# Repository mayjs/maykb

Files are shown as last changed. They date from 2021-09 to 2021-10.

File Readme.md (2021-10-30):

#  Maykb - a custom split keyboard for ISO-DE users
Maykb is a split keyboard using a staggered ISO layout including the ISO-Enter. Other features are one duplicated column in the middle (for people who don't always use the same finger for those middle keys) and the inclusion of an additional key left of the `h` which I use as a backspace key.

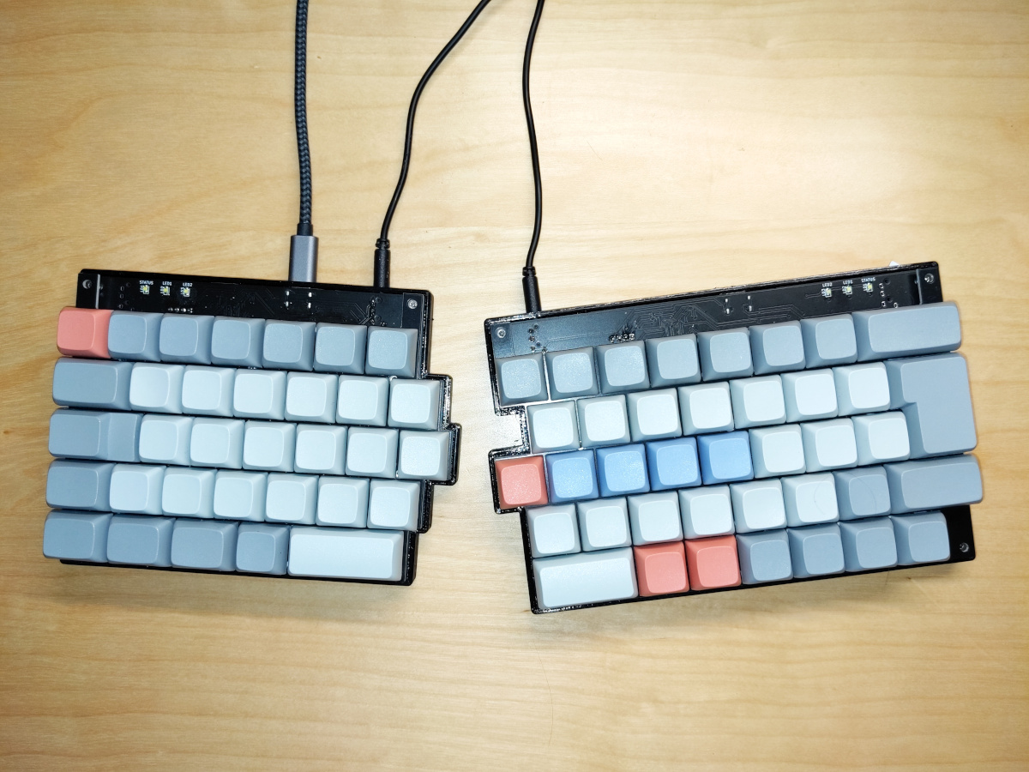
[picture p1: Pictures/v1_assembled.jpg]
Assembled Keyboard


## PCB
The PCBs for maykb are based on a STM32F103 and Cherry MX switches.
Both halves communicate using a UART interface and are equipped to be chainable, i.e. you could chain together more keyboards so you could add a numpad or a dedicated macropad if you wanted to.

There is also no fixed host MCU; both sides can act as the host and communicate over USB.

The initial revision of the PCB has one flaw: The voltage regulator for the MCU is not enabled properly due to a enable pin polarity mistake. Fixing this mistake involves lifting a pin of that regulator and wiring it properly.
I plan to replace the regulator eventually and fix the schematic and layout at that point as well.
As far as I know, there are no other hardware issues that would keep you from building one of these keyboards.

## Firmware
### Application
The firmware for the keyboard is written in Rust and uses [keyberon](https://github.com/TeXitoi/keyberon).
You need to build two different firmware versions for the left and right side so the firmware knows which part of the matrix it's working on.

### Bootloader
I'm using a slightly modified version of the [stm32duino-bootloader](https://github.com/rogerclarkmelbourne/STM32duino-bootloader).
This allows easy DFU flashing when you change the firmware.
The bootloader can be entered by holding the top left key of each side or by holding down the bootloader key on the bottom side of the PCB.

## Construction
The maykb case is designed to be 3D-printed and design files are available as OpenSCAD code.
It should be easy to adjust the code to allow for different screw tolerances or even brass screw inserts.

As a small novelty, the plates can be manufactured as aluminium PCBs (I had good results with JLCPCB), which is cheaper than all laser cutting services I was able to locate.
It should also be possible to export the plate PCB files as a DXF file and use another fabrication technique.

The PCB is a simple 1.6mm thick two layer PCB and should be easily manufactured at any prototyping company.

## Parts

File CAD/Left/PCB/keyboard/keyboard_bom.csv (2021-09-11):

Comment | Designator | Footprint | LCSC
CL1 | C10 | Capacitor_SMD:C_0603_1608Metric_Pad1.08x0.95mm_HandSolder | C22397
CL2 | C11 | Capacitor_SMD:C_0603_1608Metric_Pad1.08x0.95mm_HandSolder | C22397
100nF | C1,C2,C3,C4,C7,C9 | Capacitor_SMD:C_0805_2012Metric_Pad1.18x1.45mm_HandSolder | C28233
4.7uF - 10uF | C5 | Capacitor_SMD:C_0805_2012Metric_Pad1.18x1.45mm_HandSolder | C15850
1uF | C6,C8 | Capacitor_SMD:C_0603_1608Metric_Pad1.08x0.95mm_HandSolder | C1592
USB_C_Receptacle_USB2.0 | J1 | Connector_USB:USB_C_Receptacle_HRO_TYPE-C-31-M-12 | C165948
Debug | J2 | Connector_PinHeader_2.54mm:PinHeader_1x04_P2.54mm_Horizontal
Conn_Left | J3 | Random Keyboard Parts:PJ-3200B-4A-TRRS | C136687
Conn_Right | J4 | Random Keyboard Parts:PJ-3200B-4A-TRRS | C136687
LED | LD1,LD2,LD3 | LED_SMD:LED_0805_2012Metric_Pad1.15x1.40mm_HandSolder | C110099
SW_SPST | PB1 | Button_Switch_SMD:SW_SPST_TL3342
RESET | PB2 | Button_Switch_SMD:SW_SPST_TL3342
RExt | R12 | Resistor_SMD:R_0603_1608Metric_Pad0.98x0.95mm_HandSolder | C23228
10k | R1,R2,R3 | Resistor_SMD:R_0603_1608Metric_Pad0.98x0.95mm_HandSolder | C25804
5.1k | R4,R5 | Resistor_SMD:R_0603_1608Metric_Pad0.98x0.95mm_HandSolder | C23186
1.5k | R6 | Resistor_SMD:R_0603_1608Metric_Pad0.98x0.95mm_HandSolder | C22843
20R | R7,R8 | Resistor_SMD:R_0603_1608Metric_Pad0.98x0.95mm_HandSolder | C22950
510R | R9,R10,R11 | Resistor_SMD:R_0603_1608Metric_Pad0.98x0.95mm_HandSolder | C23193
TestPoint | TP1 | TestPoint:TestPoint_Pad_D1.0mm
USB_SBU1 | TP2 | TestPoint:TestPoint_Pad_D1.0mm
USB_SBU2 | TP3 | TestPoint:TestPoint_Pad_D1.0mm
LN1154 | U1 | Package_TO_SOT_SMD:SOT-23-5 | C236376
STM32F103C8Tx | U2 | Package_QFP:LQFP-48_7x7mm_P0.5mm | C77994
8MHz | Y1 | Crystal:Crystal_SMD_HC49-SD | C115962
1N4148 | D1,D2,D3,D4,D5,D6,D7,D8,D9,D10,D11,D12,D13,D14,D15,D16,D17,D18,D19,D20,D21,D22,D23,D24,D25,D26,D27,D28,D29,D30,D31,D32,D33,D34,D35,D36,D37,D38,D39 |  | C2128

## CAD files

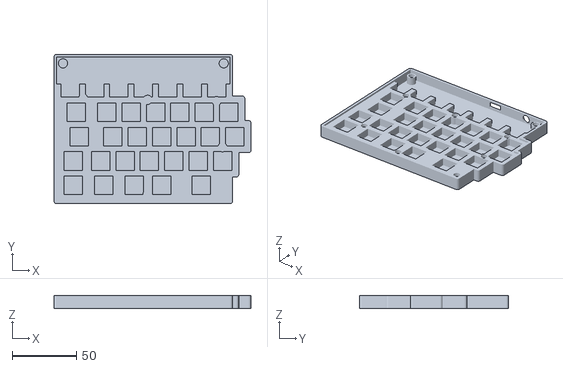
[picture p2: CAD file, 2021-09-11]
CAD/Left/Case/case_left.stl
153.8 x 116.6 x 10.0

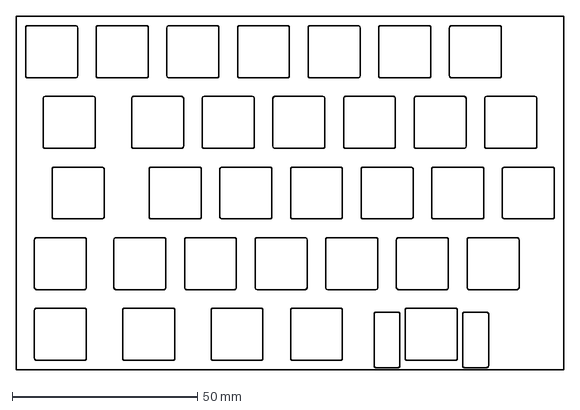
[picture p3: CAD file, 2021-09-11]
CAD/Left/Plate/#plate-20210801-131349.dxf
147.6 x 95.2 mm

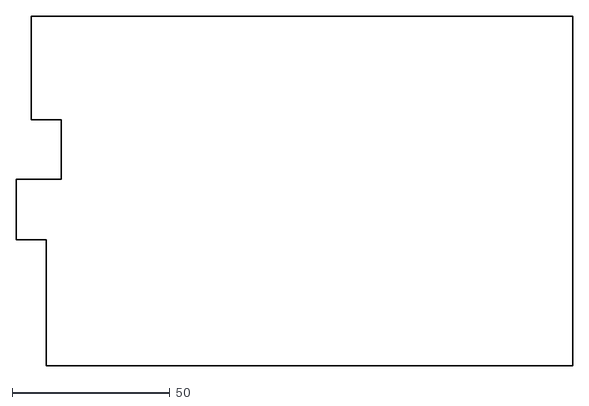
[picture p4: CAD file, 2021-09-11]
CAD/Right/Case/outline.dxf
176.5 x 110.7

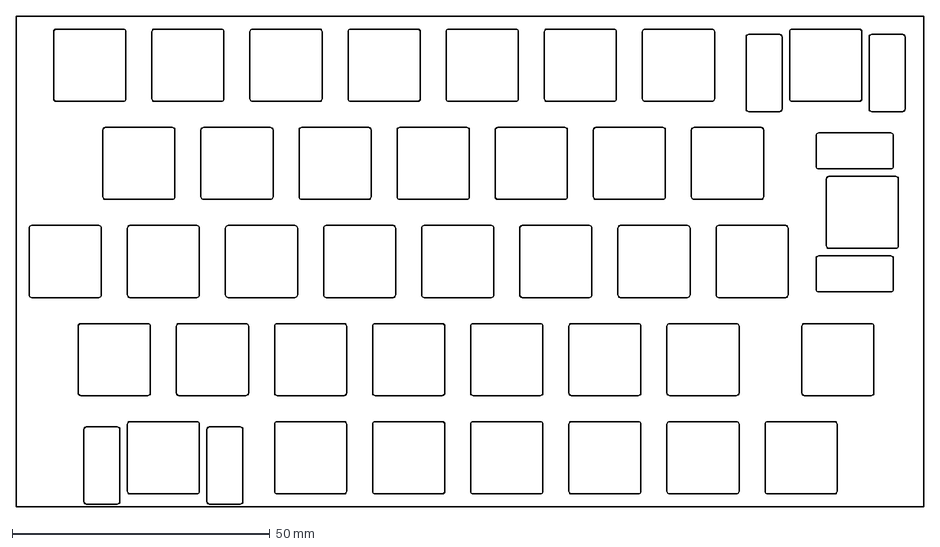
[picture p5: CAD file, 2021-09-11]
CAD/Right/Plate/plate-20210801-010555.dxf
176.2 x 95.2 mm

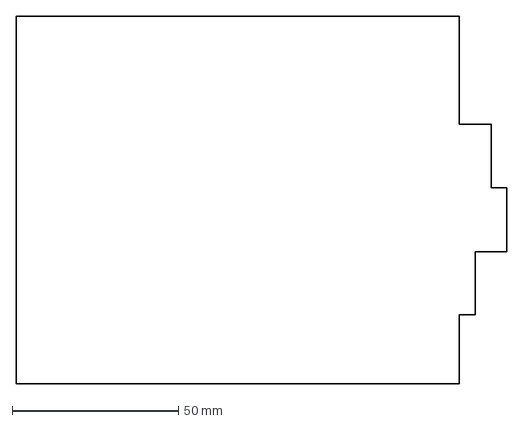
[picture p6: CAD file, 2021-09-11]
CAD/Left/Case/outline.dxf
147.8 x 110.6 mm

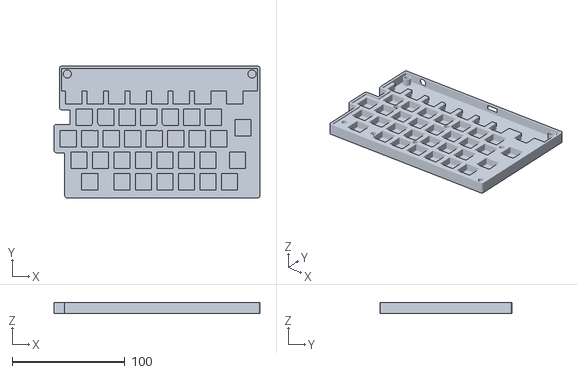
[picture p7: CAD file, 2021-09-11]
CAD/Right/Case/case_right.stl
182.5 x 116.7 x 10.0

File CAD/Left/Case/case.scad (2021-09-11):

use <mayscadlib/positioning.scad>;
use <mayscadlib/2d/shapes.scad>;
use <./footprint_centers.scad>;

$fn=100;
wall = 2;
bot_plane=wall;
play = .2;
pcb_thickness = 1.6;
screw_length=8;
pcb_pos = screw_length-pcb_thickness;
audio_jack_dia = 5;
audio_plug_dia = 6.2;
usb_c_jack_bounds = [10, 4];
switch_cutout_size = [14.5,14.5];

mounting_positions = [
  [4.06,    -4.06],
  [129.54,  -4.06],
  [19.81,   -31.50],
  [70.10,   -32.51],
  [123.95,  -33.53],
  [128.52,  -69.60],
  [23.11,   -89.92],
  [70.10,   -106.17],
  [129.54,  -106.17]
];

audio_jacks = [
  //17.65, // Skip the left jack hole
  115.72,
];

usb_c_jack = 84.56;

footprint_origin = [69.7548, 44.547];

module outline(play=5*play) {
  offset(delta=play)
  import("./outline.dxf");
}

module wall_2d() {
  difference() {
    offset(r=wall)
    outline();
    outline();
  }
}

function screw_post_outer_rad(screw_dia=3) = ((screw_dia+play)/2)+wall;

module screw_post(screw_grip=2.5, screw_length=screw_length-pcb_thickness, screw_dia=3) {
  grip_rad = (screw_dia + play)/2;
  linear_extrude(height=screw_grip)
  difference() {
    circle(r=screw_post_outer_rad(screw_dia=screw_dia));
    circle(r=grip_rad);
  }
  lift(screw_grip)
  linear_extrude(height=screw_length-screw_grip)
  difference() {
    circle(r=grip_rad+wall);
    circle(r=grip_rad+1);
  }
}

module audio_jack_cutout() {
  cutout_h = wall + play*5;
  function rad(assumed) = (assumed+play)/2;
  translate([0,cutout_h,0])
  lift(pcb_pos-rad(audio_jack_dia)+bot_plane)
  rotate([90,0,0])
  cylinder(r2=rad(audio_plug_dia), r1=rad(audio_plug_dia*1.2), h=cutout_h);
}

module usb_c_jack_cutout() {
  cutout_h = wall + play*5;
  real_bounds = usb_c_jack_bounds + [2*play, 2*play];

  translate([0,cutout_h,0])
  lift(pcb_pos-real_bounds[1]+bot_plane)
  rotate([90,0,0])
  translate([0,real_bounds[1]/2, cutout_h])
  mirror([0,0,1])
  linear_extrude(height=cutout_h, scale=1.2)
  rounded_square(size=real_bounds, corner_rad=.5, center=true);
}

module stabilization_area() {
  difference() {
    intersection(){
      outline();
      // Cut off a bit of the top post switch area
      translate([-50,-1020])
      square(size=[1000,1000]);
    }
    place([for(k=kb_footprint_centers()) [k[0] - footprint_origin[0], -k[1]+footprint_origin[1]]])
    square(switch_cutout_size,center=true);
    place(mounting_positions)
    circle(screw_post_outer_rad());
  }
}


difference() {
  union() {

    linear_extrude(height=bot_plane) {
      wall_2d();
      outline();
    }
    translate([0,0,bot_plane])
    linear_extrude(height=pcb_pos + pcb_thickness) {
      wall_2d();
    }
  }

  place([for(x=audio_jacks) [x,0,0]])
  audio_jack_cutout();

  translate([usb_c_jack,0,0])
  usb_c_jack_cutout();
}
lift(bot_plane-.01)
linear_extrude(height=pcb_pos)
stabilization_area();

place(mounting_positions) {
  lift(bot_plane)
  screw_post();
}

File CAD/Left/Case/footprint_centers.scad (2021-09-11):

function kb_footprint_centers() = [
    [107.931,86.722],
    [84.1185,86.722],
    [193.656,67.672],
    [174.606,67.672],
    [155.556,67.672],
    [136.506,67.672],
    [181.74975,143.872],
    [150.7935,143.872],
    [129.36225,143.872],
    [105.54975,143.872],
    [117.456,67.672],
    [81.73725,143.872],
    [198.4185,124.822],
    [179.3685,124.822],
    [160.3185,124.822],
    [141.2685,124.822],
    [122.2185,124.822],
    [103.1685,124.822],
    [81.73725,124.822],
    [207.9435,105.772],
    [188.8935,105.772],
    [98.406,67.672],
    [169.8435,105.772],
    [150.7935,105.772],
    [131.7435,105.772],
    [112.6935,105.772],
    [86.49975,105.772],
    [203.181,86.722],
    [184.131,86.722],
    [165.081,86.722],
    [146.031,86.722],
    [126.981,86.722],
    [79.356,67.672],
    [181.74975,143.872],
];

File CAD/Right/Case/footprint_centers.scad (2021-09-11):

function kb_footprint_centers() = [
    [52.6225,94.469],
    [185.9725,75.419],
    [157.3975,75.419],
    [138.3475,75.419],
    [119.2975,75.419],
    [100.2475,75.419],
    [181.21,151.619],
    [162.16,151.619],
    [143.11,151.619],
    [124.06,151.619],
    [105.01,151.619],
    [85.96,151.619],
    [57.385,151.619],
    [188.35375,132.569],
    [162.16,132.569],
    [143.11,132.569],
    [81.1975,75.419],
    [124.06,132.569],
    [105.01,132.569],
    [85.96,132.569],
    [66.91,132.569],
    [47.86,132.569],
    [171.685,113.519],
    [152.635,113.519],
    [133.585,113.519],
    [114.535,113.519],
    [95.485,113.519],
    [62.1475,75.419],
    [76.435,113.519],
    [57.385,113.519],
    [38.335,113.519],
    [193.11625,103.994],
    [166.9225,94.469],
    [147.8725,94.469],
    [128.8225,94.469],
    [109.7725,94.469],
    [90.7225,94.469],
    [71.6725,94.469],
    [43.0975,75.419],
    [185.9725,75.419],
    [57.385,151.619],
    [193.11625,103.994],
];

function kb_mount_centers() = [
    [180.25,102.068],
    [62.25,103.068],
    [114.25,142.068],
    [119.25,103.068],
    [75.25,153.068],
    [42.25,153.068],
    [37.49,56.324],
    [201.232,56.324],
    [201.232,159.068],
];

function audio_jack_x() = [
    51.232,
    187.232,
];

function usb_c_x() = [
    129.681001,
];

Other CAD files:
CAD/Left/Plate/vec/#plate-Edge_Cuts.dxf
CAD/Right/Case/case.scad
CAD/Left/Plate/plate-20210801-131349.dxf
CAD/Left/Plate/vec/plate-Edge_Cuts.dxf

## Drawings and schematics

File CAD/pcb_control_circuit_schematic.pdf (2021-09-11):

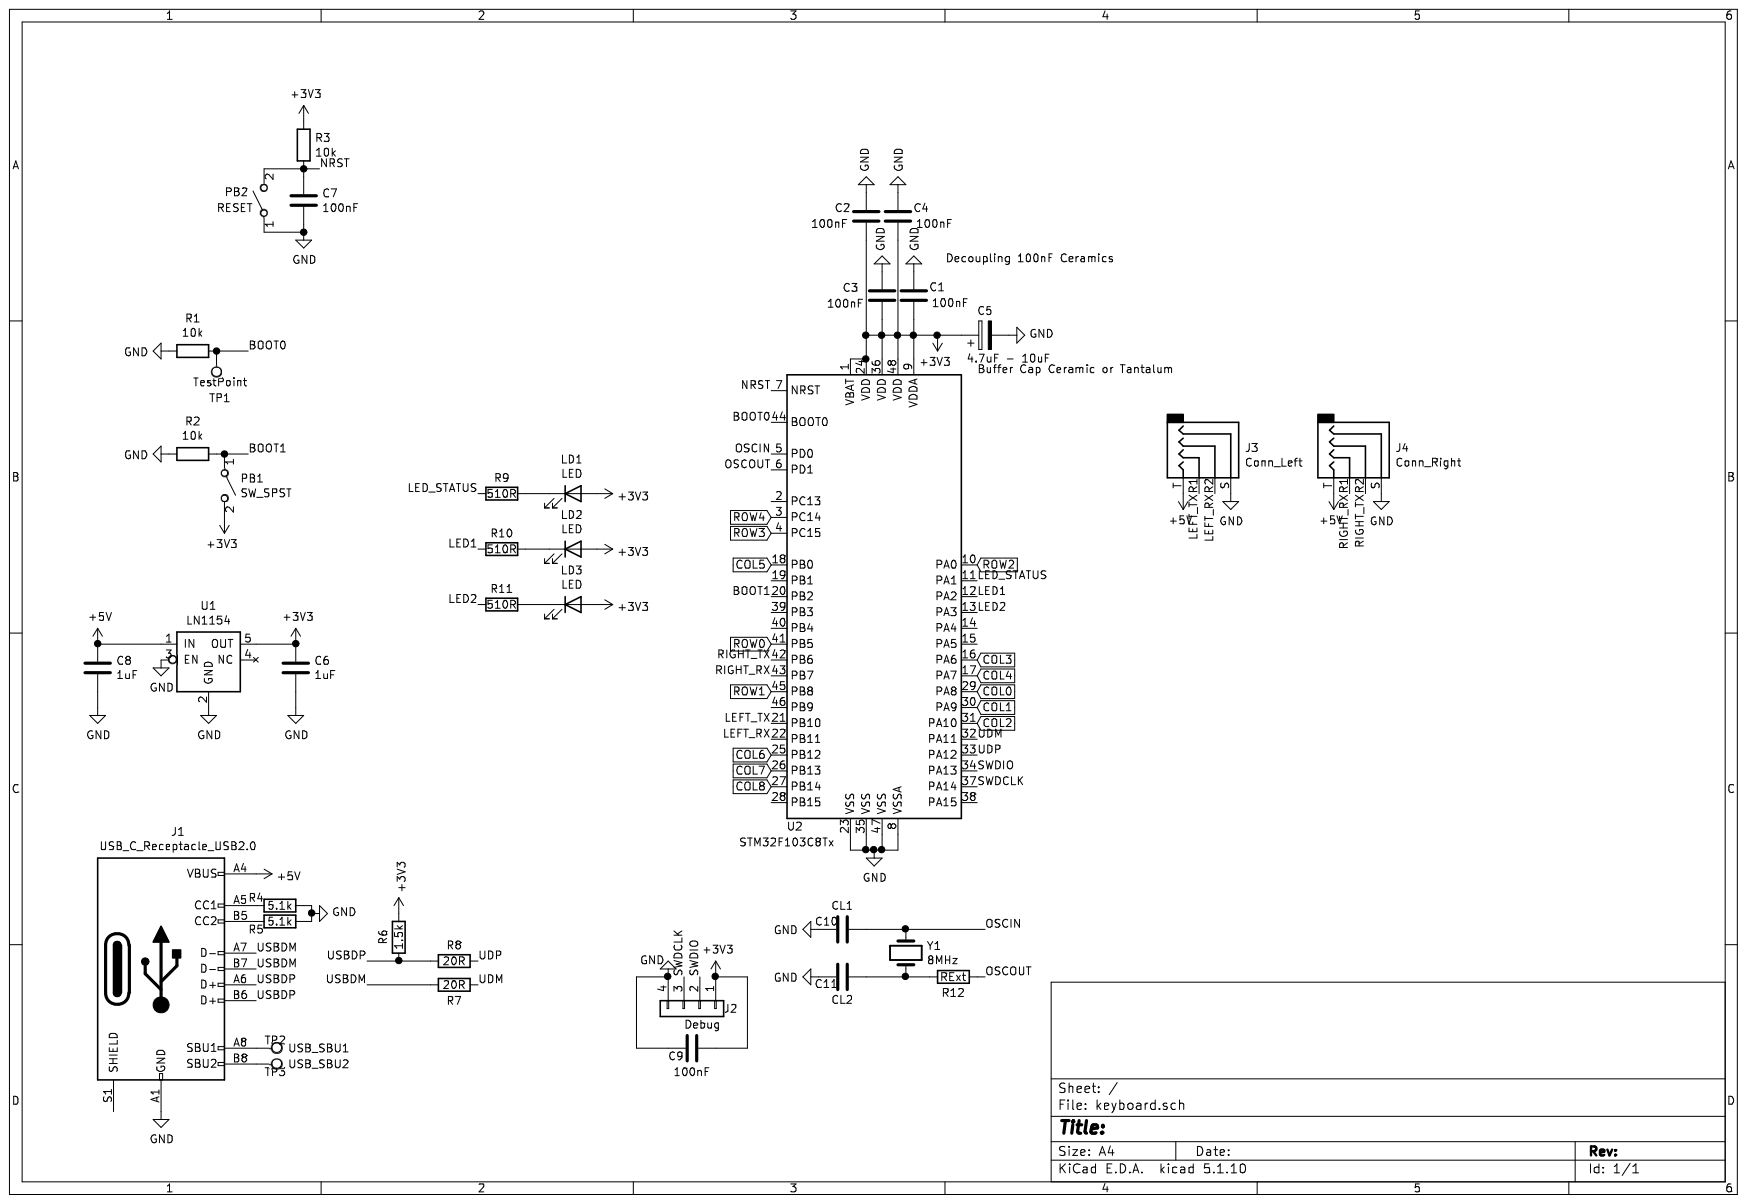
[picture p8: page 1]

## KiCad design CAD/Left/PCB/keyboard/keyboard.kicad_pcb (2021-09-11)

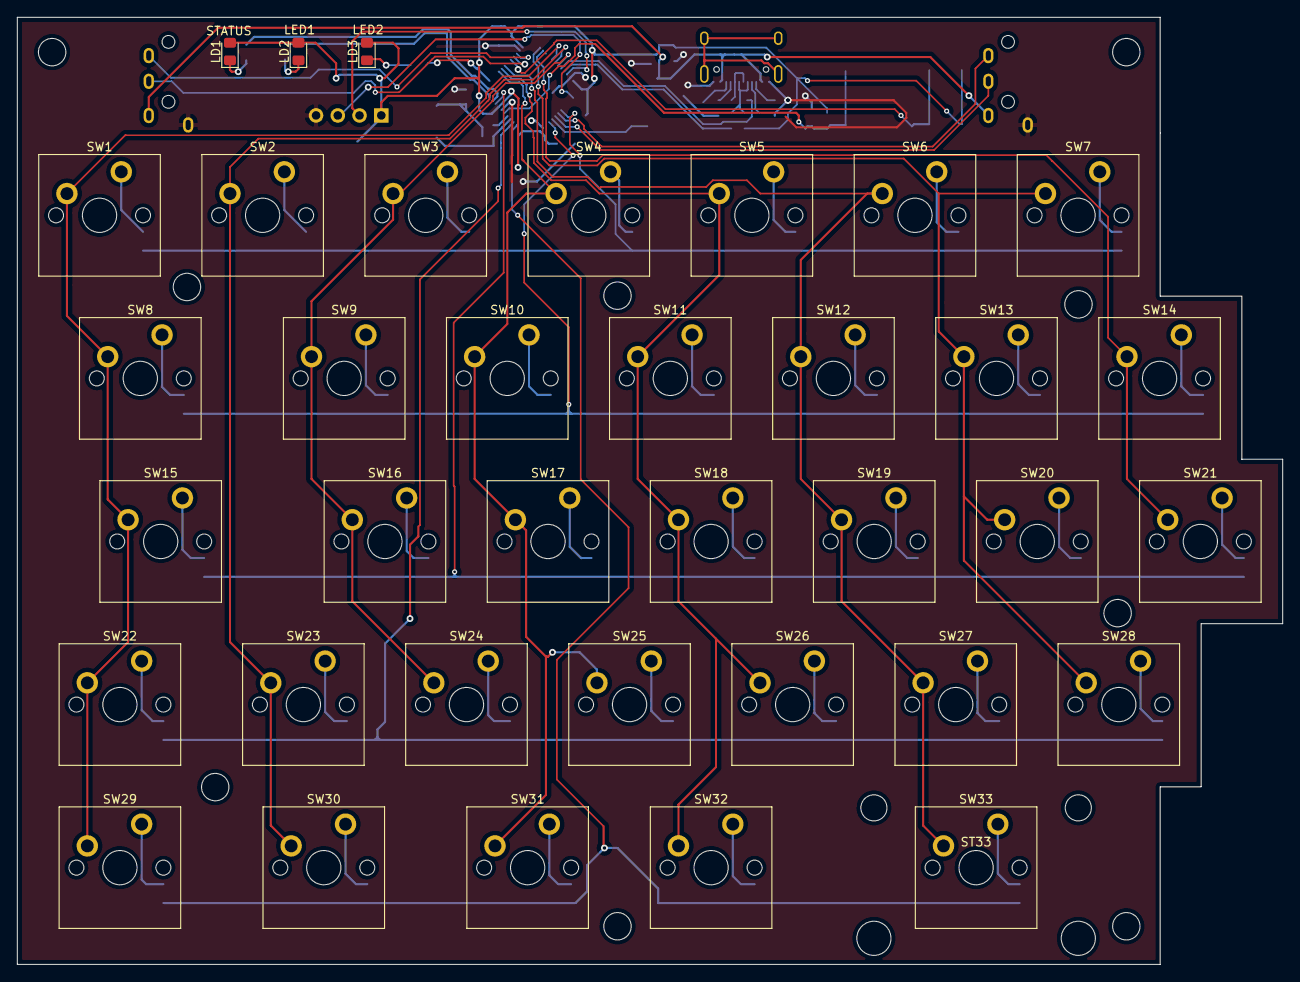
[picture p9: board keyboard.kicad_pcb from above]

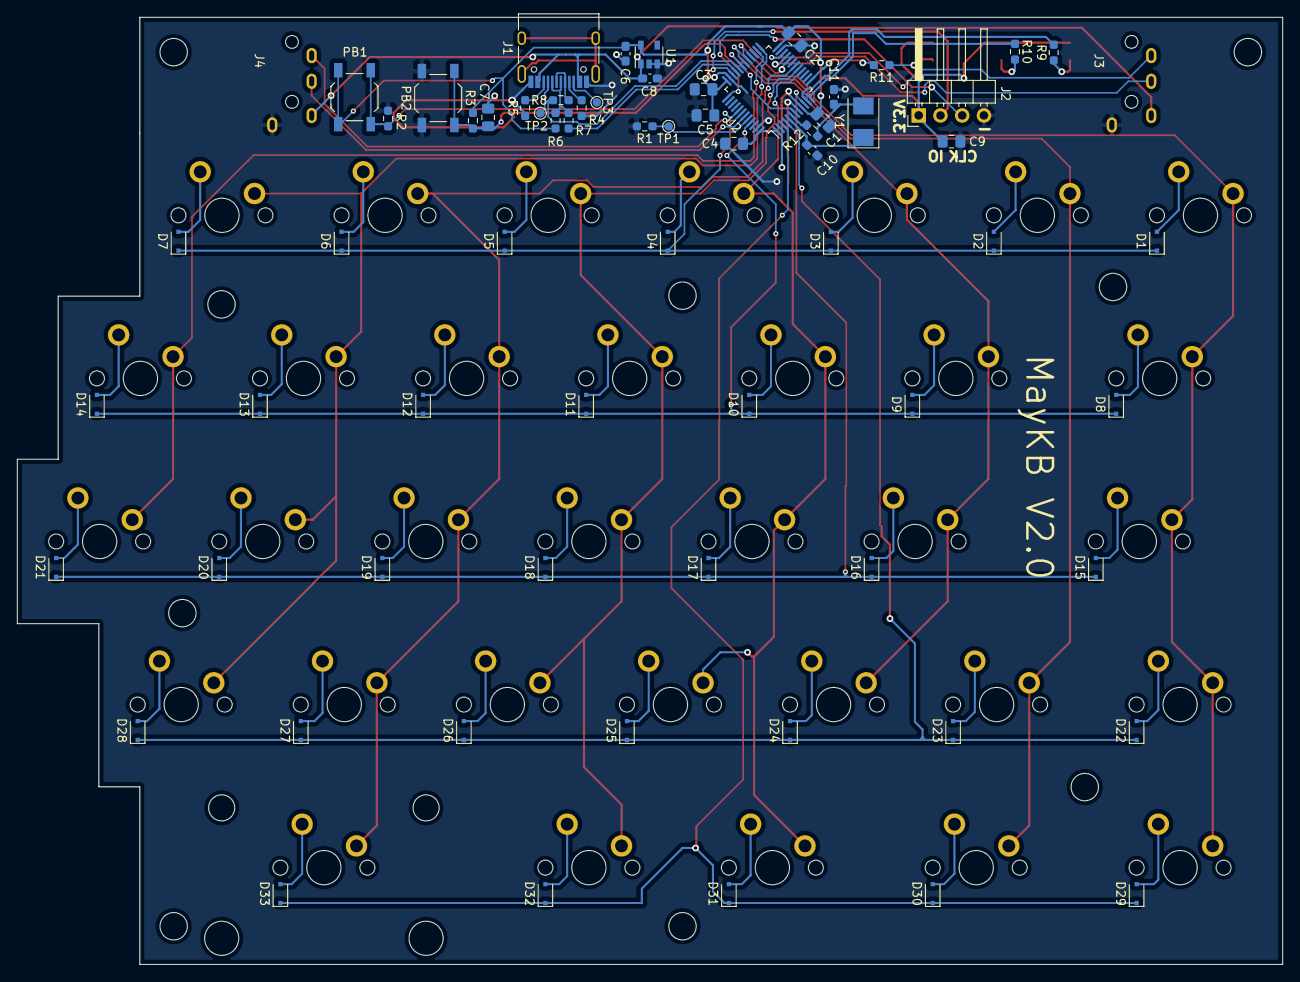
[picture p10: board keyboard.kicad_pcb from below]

Board: 2 copper layers, 147.8 x 110.6 mm, 105 parts (68 on the bottom side), 75 nets.

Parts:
C1, C2, C3, C4, C7, C9: 100nF; C_0805_2012Metric_Pad1.18x1.45mm_HandSolder
C5: 4.7uF - 10uF; C_0805_2012Metric_Pad1.18x1.45mm_HandSolder
C6, C8: 1uF; C_0603_1608Metric_Pad1.08x0.95mm_HandSolder
C10: CL1; C_0603_1608Metric_Pad1.08x0.95mm_HandSolder
C11: CL2; C_0603_1608Metric_Pad1.08x0.95mm_HandSolder
D1, D2, D3, D4, D5, D6, D7, D8, D9, D10, D11, D12, D13, D14, D15, D16, D17, D18, D19, D20, D21, D22, D23, D24, D25, D26, D27, D28, D29, D30, D31, D32, D33: D; D_SOD-323F
J1: USB_C_Receptacle_USB2.0; USB_C_Receptacle_HRO_TYPE-C-31-M-12
J2: Debug; PinHeader_1x04_P2.54mm_Horizontal
J3: Conn_Left; PJ-3200B-4A-TRRS
J4: Conn_Right; PJ-3200B-4A-TRRS
LD1, LD2, LD3: LED; LED_0805_2012Metric_Pad1.15x1.40mm_HandSolder
PB1: SW_SPST; SW_SPST_TL3342
PB2: RESET; SW_SPST_TL3342
R1, R2, R3: 10k; R_0603_1608Metric_Pad0.98x0.95mm_HandSolder
R4, R5: 5.1k; R_0603_1608Metric_Pad0.98x0.95mm_HandSolder
R6: 1.5k; R_0603_1608Metric_Pad0.98x0.95mm_HandSolder
R7, R8: 20R; R_0603_1608Metric_Pad0.98x0.95mm_HandSolder
R9, R10, R11: 510R; R_0603_1608Metric_Pad0.98x0.95mm_HandSolder
R12: RExt; R_0603_1608Metric_Pad0.98x0.95mm_HandSolder
ST33: MountingHole; Stabilizer_Cherry_MX_2u
SW1, SW2, SW3, SW4, SW5, SW6, SW7, SW9, SW10, SW11, SW12, SW13, SW14, SW16, SW17, SW18, SW19, SW20, SW21, SW23, SW24, SW25, SW26, SW27, SW28, SW32: SW_Push; SW_Cherry_MX_PCB_1.00u
SW8: SW_Push; SW_Cherry_MX_PCB_1.50u
SW15: SW_Push; SW_Cherry_MX_PCB_1.75u
SW22, SW29, SW30, SW31: SW_Push; SW_Cherry_MX_PCB_1.25u
SW33: SW_Push; SW_Cherry_MX_PCB_2.25u
TP1: TestPoint; TestPoint_Pad_D1.0mm
TP2: USB_SBU1; TestPoint_Pad_D1.0mm
TP3: USB_SBU2; TestPoint_Pad_D1.0mm
U1: LN1154; SOT-23-5
U2: STM32F103C8Tx; LQFP-48_7x7mm_P0.5mm
Y1: 8MHz; Crystal_SMD_5032-2Pin_5.0x3.2mm

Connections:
+3V3: C1.1, C2.1, C3.2, C4.1, C5.1, C6.1, C9.1, J2.1, LD1.2, LD2.2, LD3.2, PB1.2, R3.1, R6.1, U1.5, U2.1, U2.9, U2.24, U2.36, U2.48
+5V: C8.1, J1.A4, J1.A9, J1.B4, J1.B9, J3.T, J4.T, U1.1
/BOOT0: R1.1, TP1.1, U2.44
/BOOT1: PB1.1, R2.1, U2.20
/LED1: R10.2, U2.12
/LED2: R11.2, U2.13
/LED_STATUS: R9.2, U2.11
/LEFT_RX: J3.R2, U2.22
/LEFT_TX: J3.R1, U2.21
/NRST: C7.1, PB2.2, R3.2, U2.7
/OSCIN: C10.1, U2.5, Y1.1
/OSCOUT: R12.1, U2.6
/RIGHT_RX: J4.R1, U2.43
/RIGHT_TX: J4.R2, U2.42
/SWDCLK: J2.3, U2.37
/SWDIO: J2.2, U2.34
/UDM: R8.1, U2.32
/UDP: R7.1, U2.33
/USBDM: J1.A7, J1.B7, R8.2
/USBDP: J1.A6, J1.B6, R6.2, R7.2
COL0: SW1.1, SW8.1, SW15.1, SW22.1, SW29.1, U2.29
COL1: SW2.1, SW23.1, SW30.1, U2.30
COL2: SW3.1, SW9.1, SW16.1, SW24.1, U2.31
COL3: SW4.1, SW10.1, SW17.1, SW25.1, SW31.1, U2.16
COL4: SW5.1, SW11.1, SW18.1, SW26.1, SW32.1, U2.17
COL5: SW6.1, SW12.1, SW19.1, SW27.1, SW33.1, U2.18
COL6: SW7.1, SW13.1, SW20.1, SW28.1, U2.25
COL7: SW14.1, SW21.1, U2.26
GND: C1.2, C2.2, C3.1, C4.2, C5.2, C6.2, C7.2, C8.2, C9.2, C10.2, C11.1, J1.A1, J1.A12, J1.B1, J1.B12, J2.4, J3.S, J4.S, PB2.1, R1.2, R2.2, R4.1, R5.1, U1.2, U1.3, U2.8, U2.23, U2.35, U2.47
unnamed: D1.2, SW1.2
unnamed: D2.2, SW2.2
unnamed: D3.2, SW3.2
unnamed: D4.2, SW4.2
unnamed: D5.2, SW5.2
unnamed: D6.2, SW6.2
unnamed: D7.2, SW7.2
unnamed: D8.2, SW8.2
unnamed: D9.2, SW9.2
unnamed: D10.2, SW10.2
unnamed: D11.2, SW11.2
unnamed: D12.2, SW12.2
unnamed: D13.2, SW13.2
unnamed: D14.2, SW14.2
unnamed: D15.2, SW15.2
unnamed: D16.2, SW16.2
unnamed: D17.2, SW17.2
unnamed: D18.2, SW18.2
unnamed: D19.2, SW19.2
unnamed: D20.2, SW20.2
unnamed: D21.2, SW21.2
unnamed: D22.2, SW22.2
unnamed: D23.2, SW23.2
unnamed: D24.2, SW24.2
unnamed: D25.2, SW25.2
unnamed: D26.2, SW26.2
unnamed: D27.2, SW27.2
unnamed: D28.2, SW28.2
unnamed: D29.2, SW29.2
unnamed: D30.2, SW30.2
unnamed: D31.2, SW31.2
unnamed: D32.2, SW32.2
unnamed: D33.2, SW33.2
unnamed: C11.2, R12.2, Y1.2
unnamed: J1.A5, R4.2
unnamed: J1.A8, TP2.1
unnamed: J1.B5, R5.2
unnamed: J1.B8, TP3.1
unnamed: LD1.1, R9.1
unnamed: LD2.1, R10.1
unnamed: LD3.1, R11.1
ROW0: D1.1, D2.1, D3.1, D4.1, D5.1, D6.1, D7.1, U2.41
ROW1: D8.1, D9.1, D10.1, D11.1, D12.1, D13.1, D14.1, U2.45
ROW2: D15.1, D16.1, D17.1, D18.1, D19.1, D20.1, D21.1, U2.10
ROW3: D22.1, D23.1, D24.1, D25.1, D26.1, D27.1, D28.1, U2.4
ROW4: D29.1, D30.1, D31.1, D32.1, D33.1, U2.3

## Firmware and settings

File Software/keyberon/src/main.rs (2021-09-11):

#![no_main]
#![no_std]

use panic_halt as _;

use core::convert::Infallible;
use hal::prelude::*;
use hal::gpio::{Input, Output, Pxx, PullUp, PushPull, OpenDrain};
use hal::serial;
use hal::usb;
use hal::{stm32, timer};
use embedded_hal::digital::v2::OutputPin;
use keyberon::action::{k, l, m, d, Action, Action::*, HoldTapConfig};
use keyberon::debounce::Debouncer;
use keyberon::key_code::KbHidReport;
use keyberon::key_code::KeyCode::*;
use keyberon::layout::{Event, Layout};
use keyberon::matrix::{Matrix, PressedKeys};
use nb::block;
use rtic::app;
use stm32f1xx_hal as hal;
use usb_device::bus::UsbBusAllocator;
use usb_device::class::UsbClass as _;
use usb_device::device::UsbDeviceState;

type UsbClass = keyberon::Class<'static, usb::UsbBusType, ()>;
type UsbDevice = usb_device::device::UsbDevice<'static, usb::UsbBusType>;

trait ResultExt<T> {
    fn get(self) -> T;
}
impl<T> ResultExt<T> for Result<T, Infallible> {
    fn get(self) -> T {
        match self {
            Ok(v) => v,
            Err(e) => match e {},
        }
    }
}

// Taps will toggle the default layer, holding will add acurrent layer.
const FN_KEY: Action = HoldTap {
    config: HoldTapConfig::Default,
    hold: &l(1),
    tap: &d(1),
    tap_hold_interval: 0,
    timeout: 100,
};

#[rustfmt::skip]
pub static LAYERS: keyberon::layout::Layers = &[
    &[
        &[k(Grave), k(Kb1), k(Kb2), k(Kb3), k(Kb4), k(Kb5), k(Kb6), Trans, Trans, k(Kb6), k(Kb7), k(Kb8), k(Kb9), k(Kb0), k(Minus), k(Equal), Trans, k(BSpace)],
        &[k(Tab), Trans, k(Q), k(W), k(E), k(R), k(T), k(Y), Trans, Trans, k(Y), k(U), k(I), k(O), k(P), k(LBracket), k(RBracket), Trans],
        &[k(Escape), Trans, k(A), k(S), k(D), k(F), k(G), k(H), Trans, k(BSpace), k(H), k(J), k(K), k(L), k(SColon), k(Quote), k(NonUsHash), k(Enter)],
        &[k(LShift), k(NonUsBslash), k(Z), k(X), k(C), k(V), k(B), Trans, Trans, Trans, k(B), k(N), k(M), k(Comma), k(Dot), k(Slash), k(Up), k(RShift)],
        &[k(LCtrl), k(LGui), Trans, k(LAlt), FN_KEY, k(Space), Trans, Trans, Trans, Trans, k(Space), Trans, k(Enter), k(Delete), k(RAlt), k(Left), k(Down), k(Right)]
    ],
    &[
        &[Trans, k(F1), k(F2), k(F3), k(F4), k(F5), k(F6), Trans, Trans, k(F6), k(F7), k(F8), k(F9), k(F10), k(F11), k(F12), Trans, Trans],
        &[Trans, Trans, Trans, Trans, Trans, Trans, Trans, Trans, Trans, Trans, Trans, Trans, Trans, k(Kp7), k(Kp8), k(Kp9), Trans, Trans],
        &[Trans, Trans, Trans, Trans, Trans, Trans, Trans, Trans, Trans, Trans, Trans, Trans, Trans, k(Kp4), k(Kp5), k(Kp6), Trans, Trans],
        &[Trans, Trans, Trans, Trans, Trans, Trans, Trans, Trans, Trans, Trans, Trans, Trans, Trans, k(Kp1), k(Kp2), k(Kp3), Trans, Trans],
        &[Trans, Trans, Trans, Trans, d(0), Trans, Trans, Trans, Trans, Trans, Trans, Trans, Trans, Trans, k(Kp0), Trans, Trans, Trans],
    ],
];

#[derive(Debug, Clone, Copy)]
pub enum BoardType {
    Left,
    Right
}

const COLS_PER_BOARD: u8 = 9;

#[app(device = crate::hal::pac, peripherals = true)]
const APP: () = {
    struct Resources {
        usb_dev: UsbDevice,
        usb_class: UsbClass,
        matrix: Matrix<Pxx<Input<PullUp>>, Pxx<Output<PushPull>>, 9, 5>,
        debouncer: Debouncer<PressedKeys<9, 5>>,
        layout: Layout,
        timer: timer::CountDownTimer<stm32::TIM3>,

        right_tx: serial::Tx<hal::pac::USART1>,
        right_rx: serial::Rx<hal::pac::USART1>,

        left_tx: serial::Tx<hal::pac::USART3>,
        left_rx: serial::Rx<hal::pac::USART3>,

        left_buf: [u8; 4],
        right_buf: [u8; 4],

        board_type: BoardType, 

        leds: [Pxx<Output<OpenDrain>>; 3]
        /*
        transform: fn(Event) -> Event,
        tx: serial::Tx<hal::pac::USART1>,
        rx: serial::Rx<hal::pac::USART1>,
        */
    }

    #[init]
    fn init(mut c: init::Context) -> init::LateResources {
        static mut USB_BUS: Option<UsbBusAllocator<usb::UsbBusType>> = None;

        let mut flash = c.device.FLASH.constrain();
        let mut rcc = c.device.RCC.constrain();

        let mut afio = c.device.AFIO.constrain(&mut rcc.apb2);

        let clocks = rcc.cfgr
            .use_hse(8.mhz())
            .sysclk(72.mhz())
            .pclk1(36.mhz())
            .pclk2(72.mhz())
            .freeze(&mut flash.acr);

        let mut gpioa = c.device.GPIOA.split(&mut rcc.apb2);
        let mut gpiob = c.device.GPIOB.split(&mut rcc.apb2);
        let mut gpioc = c.device.GPIOC.split(&mut rcc.apb2);

        let usb = usb::Peripheral {
            usb: c.device.USB,
            pin_dm: gpioa.pa11,
            pin_dp: gpioa.pa12,
        };
        *USB_BUS = Some(usb::UsbBusType::new(usb));
        let usb_bus = USB_BUS.as_ref().unwrap();

        let usb_class = keyberon::new_class(usb_bus, ());
        let usb_dev = keyberon::new_device(usb_bus);

        let mut timer = timer::Timer::tim3(c.device.TIM3, &clocks, &mut rcc.apb1).start_count_down(1.khz());
        timer.listen(timer::Event::Update);

        let mut right_usart = serial::Serial::usart1(c.device.USART1, 
            (
                gpiob.pb6.into_alternate_push_pull(&mut gpiob.crl),
                gpiob.pb7
            ),
            &mut afio.mapr,
            serial::Config::default().baudrate(38_400.bps()).parity_even(),
            clocks,
            &mut rcc.apb2
        );
        right_usart.listen(serial::Event::Rxne);
        let (right_tx, right_rx) = right_usart.split();

        let mut left_usart = serial::Serial::usart3(c.device.USART3, 
            (
                gpiob.pb10.into_alternate_push_pull(&mut gpiob.crh),
                gpiob.pb11
            ),
            &mut afio.mapr,
            serial::Config::default().baudrate(38_400.bps()).parity_even(),
            clocks,
            &mut rcc.apb1
        );
        left_usart.listen(serial::Event::Rxne);
        let (left_tx, left_rx) = left_usart.split();

        /*
        let (pa9, pa10) = (gpioa.pa9, gpioa.pa10);
        let pins = cortex_m::interrupt::free(move |cs| {
            (pa9.into_alternate_af1(cs), pa10.into_alternate_af1(cs))
        });
        let mut serial = serial::Serial::usart1(c.device.USART1, pins, 38_400.bps(), &mut rcc);
        serial.listen(serial::Event::Rxne);
        let (tx, rx) = serial.split();
        */

        let mut matrix = Matrix::new(
            [
                gpioa.pa8.into_pull_up_input(&mut gpioa.crh).downgrade(),
                gpioa.pa9.into_pull_up_input(&mut gpioa.crh).downgrade(),
                gpioa.pa10.into_pull_up_input(&mut gpioa.crh).downgrade(),
                gpioa.pa6.into_pull_up_input(&mut gpioa.crl).downgrade(),
                gpioa.pa7.into_pull_up_input(&mut gpioa.crl).downgrade(),
                gpiob.pb0.into_pull_up_input(&mut gpiob.crl).downgrade(),
                gpiob.pb12.into_pull_up_input(&mut gpiob.crh).downgrade(),
                gpiob.pb13.into_pull_up_input(&mut gpiob.crh).downgrade(),
                gpiob.pb14.into_pull_up_input(&mut gpiob.crh).downgrade(),
            ],
            [

                gpiob.pb5.into_push_pull_output(&mut gpiob.crl).downgrade(),
                gpiob.pb8.into_push_pull_output(&mut gpiob.crh).downgrade(),
                gpioa.pa0.into_push_pull_output(&mut gpioa.crl).downgrade(),
                gpioc.pc15.into_push_pull_output(&mut gpioc.crh).downgrade(),
                gpioc.pc14.into_push_pull_output(&mut gpioc.crh).downgrade(),
            ],
        ).get();

        /* Bootloader decision, unfortunately we have to scan the full matrix here since Keyberon
         * has no better API right now */
        if matrix.get().unwrap().0[0][0] {
            let bkp = rcc
                .bkp
                .constrain(c.device.BKP, &mut rcc.apb1, &mut c.device.PWR);

            reboot_bootloader(bkp);
        }

        let leds = [
            gpioa.pa1.into_open_drain_output(&mut gpioa.crl).downgrade(),
            gpioa.pa2.into_open_drain_output(&mut gpioa.crl).downgrade(),
            gpioa.pa3.into_open_drain_output(&mut gpioa.crl).downgrade(),
        ];

        init::LateResources {
            usb_dev,
            usb_class,
            timer,
            debouncer: Debouncer::new(PressedKeys::default(), PressedKeys::default(), 5),
            matrix,
            layout: Layout::new(LAYERS),
            board_type: BoardType::Right,

            left_tx,
            left_rx,
            left_buf: [0; 4],

            right_tx,
            right_rx,
            right_buf: [0; 4],

            leds
        }
    }

    #[task(binds = USB_HP_CAN_TX, priority = 4, resources = [usb_dev, usb_class])]
    fn usb_tx(c: usb_tx::Context) {
        usb_poll(c.resources.usb_dev, c.resources.usb_class);
    }

    #[task(binds = USB_LP_CAN_RX0, priority = 4, resources = [usb_dev, usb_class])]
    fn usb_rx(c: usb_rx::Context) {
        usb_poll(c.resources.usb_dev, c.resources.usb_class);
    }

    // TODO: Pipe from right to left side and vice versa
    #[task(binds = USART1, priority = 5, spawn = [handle_event], resources = [right_rx, right_buf])]
    fn uart_right_rx(c: uart_right_rx::Context) {
        if let Some(event) = read_packet(c.resources.right_rx, c.resources.right_buf) {
            c.spawn.handle_event(Some(event)).unwrap();
        }
    }

    #[task(binds = USART3, priority = 5, spawn = [handle_event], resources = [left_rx, left_buf])]
    fn uart_left_rx(c: uart_left_rx::Context) {
        if let Some(event) = read_packet(c.resources.left_rx, c.resources.left_buf) {
            c.spawn.handle_event(Some(event)).unwrap();
        }
    }
    
    #[task(priority = 3, capacity = 8, resources = [usb_dev, usb_class, layout, leds])]
    fn handle_event(mut c: handle_event::Context, event: Option<Event>) {
        match event {
            None => c.resources.layout.tick(),
            Some(e) => {
                c.resources.layout.event(e);
                return;
            }
        };

        /* Update LED states */
        let mut layer = c.resources.layout.current_layer();
        for led in c.resources.leds {
            if layer & 1 != 0 {
                led.set_low().unwrap();
            } else {
                led.set_high().unwrap();
            }
            layer >>= 1;
        }

        let report: KbHidReport = c.resources.layout.keycodes().collect();
        if !c
            .resources
            .usb_class
            .lock(|k| k.device_mut().set_keyboard_report(report.clone()))
        {
            return;
        }
        if c.resources.usb_dev.lock(|d| d.state()) != UsbDeviceState::Configured {
            return;
        }
        while let Ok(0) = c.resources.usb_class.lock(|k| k.write(report.as_bytes())) {}
    }

    #[task(
        binds = TIM3,
        priority = 2,
        resources = [usb_dev, usb_class, matrix, debouncer, timer, layout, right_tx, left_tx, board_type],
        spawn = [handle_event]
    )]
    fn tick(c: tick::Context) {
        c.resources.timer.clear_update_interrupt_flag();

        let bt = *c.resources.board_type;
        for event in c
            .resources
            .debouncer
            .events(c.resources.matrix.get().get())
            .map(|e| translate(bt, e))
        {
            for &b in &ser(event) {
                block!(c.resources.right_tx.write(b)).get();
                block!(c.resources.left_tx.write(b)).get();
            }
            c.spawn.handle_event(Some(event)).unwrap();
        }
        c.spawn.handle_event(None).unwrap();
    }

    // RTIC requires that unused interrupts are declared in an extern block when
    // using software tasks; these free interrupts will be used to dispatch the
    // software tasks.
    extern "C" {
        fn EXTI0();
    }
};

fn usb_poll(usb_dev: &mut UsbDevice, keyboard: &mut UsbClass) {
    if usb_dev.poll(&mut [keyboard]) {
        keyboard.poll();
    }
}

fn de(bytes: &[u8]) -> Result<Event, ()> {
    match *bytes {
        [b'P', i, j, b'\n'] => Ok(Event::Press(i, j)),
        [b'R', i, j, b'\n'] => Ok(Event::Release(i, j)),
        _ => Err(()),
    }
}
fn ser(e: Event) -> [u8; 4] {
    match e {
        Event::Press(i, j) => [b'P', i, j, b'\n'],
        Event::Release(i, j) => [b'R', i, j, b'\n'],
    }
}

fn read_packet(rx: &mut impl embedded_hal::serial::Read<u8>, buffer: &mut [u8; 4]) -> Option<Event> {
    if let Ok(b) = rx.read() {
        buffer.rotate_left(1);
        buffer[3] = b;

        if buffer[3] == b'\n' {
            if let Ok(event) = de(&buffer[..]) {
                Some(event)
            } else {
                None
            }
        } else {
            None
        }
    } else {
        None
    }
    
}

fn translate(board_type: BoardType, event: Event) -> Event {
    match board_type {
        BoardType::Left => event,
        BoardType::Right => event.transform(|i,j| (i, COLS_PER_BOARD + j))

    }
}

/* This routine is copied from the great polymer firmware: https://gitlab.com/polymer-kb/firmware/polymer/-/blob/master/src/reboot.rs */
pub fn reboot_bootloader(_: stm32f1xx_hal::backup_domain::BackupDomain) -> ! {
    unsafe {
        // Note: Using raw offsets here because it's wrong in the upstream stm32f1 crate.
        const BKP_BASE: usize = 0x4000_6C00;
        const BKP_DR10_OFF: usize = 0x28;
        core::ptr::write_volatile((BKP_BASE + BKP_DR10_OFF) as *mut _, 0x424C)
    };
    reboot();
}

pub fn reboot() -> ! {
    stm32f1xx_hal::stm32::SCB::sys_reset()
}

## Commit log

2021-09-11 Added v2.0 PCB designs. Note: The voltage regulator is not working in this design
    [keyboard-B_Cu.gbr, keyboard-B_Mask.gbr, keyboard-B_Paste.gbr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]
2021-09-11 Added Plate designs. Plates are meant to be manufactured as aluminum PCBs
    [#plate-20210801-131349.dxf, #plate-Edge_Cuts.dxf, plate-20210801-010555.dxf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]
2021-09-11 Added schematic of the shared control circuitry
2021-09-11 Added a simple script to extract footprint positions from keycad footprint reports
2021-09-11 Added case design files
    [case.scad, case_left.stl, case_right.stl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]
2021-09-11 Added CAD license information
